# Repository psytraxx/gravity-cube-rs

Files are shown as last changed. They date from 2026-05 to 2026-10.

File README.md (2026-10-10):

# Gravity Cube - Rust Edition

A **fluid physics simulation** of gravity-responsive particles on a 3D LED cube, implemented in Rust using hexagonal architecture. Available in two flavors:

- **Firmware**: Runs on ESP32 hardware with BMI160 IMU and WS2812 LEDs
- **Desktop**: Interactive 3D visualization on macOS/Linux with GPU-accelerated rendering

Both versions share the same fluid physics simulation core with continuous particle movement, velocity tracking, and collision detection, demonstrating the power of hexagonal architecture for code reuse across platforms.

**Enclosure:** a 3D-printable translucent case for the cube. You can [view it in 3D and download the STLs](https://psytraxx.github.io/gravity-cube-rs/voxel-shell/viewer.html). Details are in [Enclosure](#-enclosure).

---

## Project Structure

This project uses a Cargo workspace with three crates:

```
gravity-cube-rs/
├── Cargo.toml              # Workspace root
├── core/                   # Platform-agnostic library
│   ├── src/
│   │   ├── effect.rs       # SimulationEffect trait
│   │   ├── effects/        # Simulation implementations (fluid, boids)
│   │   ├── physics_utils.rs # Shared physics utilities
│   │   └── types.rs        # Domain types (Particle, Vector3D, etc.)
│   └── Cargo.toml
├── firmware/               # ESP32 firmware
│   ├── src/
│   │   ├── main.rs         # Firmware entry point
│   │   └── adapters/       # BMI160 IMU, WS2812 LED adapters
│   ├── build.rs
│   ├── .cargo/config.toml  # ESP32 target configuration
│   └── Cargo.toml
├── case/                   # 3D-printable enclosure (published to GitHub Pages)
│   ├── concepts.html       # Comparison of five frame concepts
│   ├── voxel-shell/        # STLs, generator, fit checks, 3D viewer
│   └── voxel-shell-16x16/  # same enclosure for 16x16 flexible panels
└── desktop/                # Desktop simulator
    ├── shaders/            # WGSL shaders (vertex, fragment, wireframe)
    ├── src/
    │   ├── main.rs         # Desktop entry point
    │   ├── renderer3d.rs   # GPU-accelerated voxel renderer
    │   ├── camera.rs       # Static perspective camera
    │   ├── cube_transform.rs # Rotation and gravity transform
    │   └── input.rs        # Mouse/keyboard input handling
    └── Cargo.toml
```

---

## Architecture

Both versions follow **Hexagonal Architecture** (Ports and Adapters pattern): the core crate defines the domain and platform adapters feed it gravity and render its particles:

```
┌─────────────────────────────────────────────┐
│          Application Layer                  │
│   (ESP32 async / Desktop event loop)       │
└─────────────────┬───────────────────────────┘
                  │
┌─────────────────┴───────────────────────────┐
│          Domain Layer (core crate)          │
│  ┌─────────────────────────────────────┐   │
│  │ SimulationEffect Trait               │   │
│  │ - Common interface for all effects   │   │
│  └─────────────────────────────────────┘   │
│  ┌─────────────────────────────────────┐   │
│  │ Effect Implementations               │   │
│  │ - FluidSimulation (particle physics) │   │
│  │ - BoidsSimulation (flocking behavior)│   │
│  └─────────────────────────────────────┘   │
│  ┌─────────────────────────────────────┐   │
│  │ Physics Utilities                    │   │
│  │ - Boundary collision detection       │   │
│  │ - Speed clamping & distance calc     │   │
│  └─────────────────────────────────────┘   │
│  ┌─────────────────────────────────────┐   │
│  │ Domain Types                         │   │
│  │ - Particle (pos + velocity)          │   │
│  │ - Vector3D, Position, Pixel, Color   │   │
│  └─────────────────────────────────────┘   │
└─────────────────┬───────────────────────────┘
                  │
         ┌────────┴─────────┐
         │                  │
    ┌────┴─────┐      ┌─────┴────┐
    │ Firmware │      │ Desktop  │
    │ adapters │      │ adapters │
    ├──────────┤      ├──────────┤
    │ BMI160   │      │ Mouse/   │
    │ (gravity)│      │ keyboard │
    │ WS2812   │      │ (gravity)│
    │ (LEDs)   │      │ wgpu     │
    │          │      │ renderer │
    └──────────┘      └──────────┘
```

---

## 🎮 Desktop Simulator (macOS/Linux)

Interactive 3D visualization with GPU-accelerated rendering and fluid physics.

### Features

- **GPU Rendering**: wgpu 30-based instanced voxel rendering with WGSL shaders
- **Fluid Simulation**: 256 particles with continuous positions, velocity tracking, and collisions
- **Interactive Gravity**: Rotate cube with mouse/keyboard to change gravity direction
- **Real-time Updates**: Physics runs every frame (~60 FPS) for smooth animation
- **Visual Feedback**: Speed-based brightness using HSV color system

### Requirements

- macOS (Apple Silicon or Intel) or Linux
- Rust stable toolchain
- GPU with Vulkan/Metal/DX12 support

### Building

```bash
# Build desktop version (auto-detects target)
cargo build -p gravity-cube-desktop --release
```

### Running

```bash
# macOS
cargo run -p gravity-cube-desktop --release

# Linux (use X11 backend for best compatibility)
WINIT_UNIX_BACKEND=x11 cargo run -p gravity-cube-desktop --release

```

### Controls

- **Mouse Drag**: Rotate cube (changes gravity in local space)
- **Arrow Keys**: Alternative rotation (Up/Down = pitch, Left/Right = yaw)
- **Escape**: Exit

The cube rotates based on your input, and world gravity (always pointing down) is transformed into the cube's local coordinate system. This creates realistic fluid behavior as you tilt the cube!

### Configuration

The desktop uses `Config::default()` (see `core/src/types.rs`):

```rust
Config {
    cube_size: 8,
    num_particles: 256,
    delay_ms: 35,                // Firmware frame delay (desktop updates every frame)
    color: Color::DEFAULT,
}
```

The physics tuning constants (gravity, damping, max velocity, smoothing, decay, collision repulsion/damping) are compile-time constants at the top of `core/src/effects/fluid.rs`.

---

## 🔌 ESP32 Firmware

Runs on ESP32 hardware with real IMU sensor and LED cube.

### Hardware Requirements

- **MCU**: ESP32 (tested on ESP32, not ESP32-S3)
- **IMU**: BMI160 accelerometer (SPI)
- **LEDs**: 384× WS2812B (6 panels of 8×8)
- **LED Control**: RMT peripheral via GPIO 16

### Pin Configuration

**BMI160 IMU (SPI)**:
- MOSI: GPIO 23
- MISO: GPIO 19
- SCLK: GPIO 18
- CS: GPIO 5

**WS2812 LEDs (RMT)**:
- DATA: GPIO 16

### Prerequisites

1. Install ESP Rust toolchain:
```bash
# Install espup
cargo install espup

# Install ESP toolchain
espup install

# Source the environment (add to ~/.zshrc or ~/.bashrc)
. $HOME/export-esp.sh
```

2. Install espflash:
```bash
cargo install espflash
```

### Building

```bash
# Make sure the Xtensa toolchain (incl. xtensa-esp32-elf-gcc linker) is on PATH
. $HOME/export-esp.sh

# Navigate to firmware directory
cd firmware

# Build firmware
cargo build --release
```

### Flashing to ESP32

```bash
# Flash and monitor (automatically detects USB port)
cargo run --release

# Or specify port explicitly
espflash flash --monitor target/xtensa-esp32-none-elf/release/firmware
```

### Configuration

The firmware also uses `Config::default()` in `firmware/src/main.rs` (8×8×8 cube, 256 particles, 35ms frame delay, ~28 FPS). Override fields there if the ESP32 can't keep up, e.g. lower `num_particles`.

The physics tuning constants (gravity, damping, max velocity, smoothing, decay, collision repulsion/damping) are compile-time constants at the top of `core/src/effects/fluid.rs`.

### Troubleshooting

If BMI160 initialization fails:
- Check SPI wiring matches pin configuration above
- Verify 3.3V power supply to IMU
- Check SPI bus speed (1 MHz default)

If LEDs don't light:
- Verify GPIO 16 connection to LED data line
- Check 5V power supply to LED strips (384 LEDs draw significant current)
- Confirm LED count matches configuration (384 LEDs)

---

## 📦 Enclosure

The **Voxel Shell** is an 89.6 mm cube made of six mitred face shells, printed in translucent resin. Each shell holds one 65 × 66 mm WS2812 8×8 panel behind an 8×8 light grid and a diffuser skin, so every LED shows as a square pixel. A snap-in USB-C socket and an SS12F15 slide switch sit on the bottom front edge.

- [Interactive 3D viewer and STL downloads](https://psytraxx.github.io/gravity-cube-rs/voxel-shell/viewer.html)
- [Frame concepts that were compared](https://psytraxx.github.io/gravity-cube-rs/concepts.html)
- Source, parts list and assembly steps: [`case/voxel-shell/README.md`](case/voxel-shell/README.md)
- 16×16 version (183.6 mm cube, flexible 160 × 160 mm panels): [3D viewer](https://psytraxx.github.io/gravity-cube-rs/voxel-shell-16x16/viewer.html), [`case/voxel-shell-16x16/README.md`](case/voxel-shell-16x16/README.md)

The site is published from `case/` by `.github/workflows/pages.yml` on every push to `main` that changes it.

---

## 🔬 How It Works

### Fluid Physics Simulation (Shared Core)

1. **Gravity Input**:
   - Firmware: BMI160 accelerometer reads 3-axis acceleration
   - Desktop: World gravity transformed to cube's local coordinate system based on rotation

2. **Particle System**:
   - 256 particles by default (`Config::default()`)
   - Each particle has continuous f32 position (x, y, z) and velocity (vx, vy, vz) vectors
   - Particles initialized in bottom half of cube (like water filling halfway)

3. **Physics Update (every frame)**:
   - **Velocity Update**: `v = v * smoothing + (gravity * strength)`
     - Smoothing factor: 0.9 (creates smooth acceleration)
     - Gravity strength: 0.08
   - **Velocity Clamping**: Limit to ±0.6 max velocity
   - **Position Update**: `position += velocity`
   - **Boundary Collision**: Reflect velocity with 0.92 damping when hitting walls
   - **Velocity Decay**: `v *= 0.95` (simulates friction/air resistance)
   - **Particle Collision** (O(n²)):
     - Detect particles within distance < 1.0
     - Separate overlapping particles with repulsion force
     - Average velocities for energy conservation

4. **Display Update**:
   - Continuous particle positions rounded to nearest grid cell
   - Firmware: Map 3D grid positions to 2D LED panel indices
   - Desktop: Keep fastest particle per cell for brightness feedback, render with GPU instancing

### Panel Mapping (Firmware Only)

The physical LED cube has 6 panels, each with different orientations:

- Pre-computed lookup table (512 entries for 8³ positions)
- Handles rotations: 0°, 90°, 180°, 270°
- Applies X/Y axis inversions per panel
- Determines which panels each 3D position touches

### 3D Rendering (Desktop Only)

- **Instanced Voxel Rendering**: Single draw call for all visible voxels
- **Particle-to-Voxel Conversion**: Continuous positions rounded to discrete grid cells
- **Instance Data**: Voxel position (x,y,z), HSV-based color with speed brightness
- **WGSL Shaders** (in `desktop/shaders/`):
  - `vertex3d.wgsl`: Positions voxel instances with model transformation
  - `fragment3d.wgsl`: Directional lighting
  - `wireframe.wgsl`: Cube outline
- **Depth Buffer**: GPU handles depth sorting automatically

---

## 🏗️ Benefits of Hexagonal Architecture

1. **Code Reuse**: Same physics simulation runs on ESP32 and macOS
2. **Testability**: Domain logic can be tested without hardware
3. **Flexibility**: Easy to add new platforms (e.g., Raspberry Pi, Web)
4. **Maintainability**: Clear separation of concerns
5. **Portability**: Domain layer is platform-agnostic (no_std compatible)

---

## 🧪 Testing

The core library includes comprehensive unit tests for physics utilities and simulation effects.

### Running Tests

```bash
# Test core library (platform-agnostic)
cargo test -p gravity-cube-core

# Test desktop simulator
cargo test -p gravity-cube-desktop
```

### Note on Floating-Point Precision

The core library uses `micromath` for no_std compatibility, which provides fast approximations rather than exact floating-point calculations. Physics tests use tolerances of 0.01-0.02 to account for approximation errors (~2-3% for square roots). This prioritizes real-time performance over mathematical precision, which is appropriate for visual simulations.

---

## 🔍 Code Quality

After every code change, run clippy and fmt to keep the code clean:

```bash
# Format core and desktop (skip firmware — requires ESP toolchain)
cargo fmt -p gravity-cube-core -p gravity-cube-desktop

# Lint with warnings as errors
cargo clippy -p gravity-cube-core -p gravity-cube-desktop -- -D warnings
```

---

## 📦 Dependencies

### Shared (Core)
- `micromath`: Fast floating-point math (no_std compatible)

### Firmware
- `esp-hal`: ESP32 hardware abstraction
- `esp-rtos`: RTOS integration for Embassy
- `embassy-executor`, `embassy-time`: Async runtime
- `bmi160`: IMU driver
- `esp-hal-smartled`: WS2812 LED driver (RMT)

### Desktop
- `wgpu` (v30): GPU graphics API (Metal/Vulkan/DX12)
- `winit` (v0.30): Window and input handling
- `glam` (v0.34): 3D math library
- `pollster`: Async executor for setup
- `rand`: Random number generation
- `bytemuck`: Safe GPU buffer casting
- `log` + `env_logger`: Logging

---

## 🎯 Future Enhancements

- [ ] Web version (WASM + WebGPU)
- [ ] VR support (OpenXR)
- [ ] Network sync (control firmware from desktop)
- [ ] Multiple cube sizes (4×4×4, 16×16×16)
- [ ] Different physics modes (bounce, attract, repel)
- [ ] UI overlay for real-time parameter tweaking

---

## 📝 License

Same as the original Gravity Cube project.

Original C implementation: https://github.com/Oachristensen/Gravity-Cube

---

## 🙏 Credits

- **Original Project**: [Gravity Cube by Oachristensen](https://github.com/Oachristensen/Gravity-Cube)
- **Rust Port**: Implements the same physics with type safety and cross-platform support
- **Architecture**: Hexagonal (Ports & Adapters) pattern for maximum flexibility

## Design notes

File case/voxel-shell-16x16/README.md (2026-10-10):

# Voxel Shell 16×16 enclosure

The Voxel Shell scaled up for six flexible 160 × 160 mm WS2812 16×16 panels
(10 mm pitch, 256 LEDs each, 1536 LEDs in total). The design is the same as the
[8×8 Voxel Shell](../voxel-shell/README.md):

- six mitred, translucent face shells with funnel light cells;
- a 1.0 mm diffuser skin and every wall at least 1.0 mm;
- all 12 edges bevelled;
- a USB-C socket and SS12F15 switch on the bottom front bevel.

The result is a **183.6 mm** cube with a 174 mm lit area on each face.

Every STL here is generated by `../voxel-shell/generate.py` with
`VOXEL_PROFILE=16x16`, and all fit and printability checks pass.

View it in 3D: <https://psytraxx.github.io/gravity-cube-rs/voxel-shell-16x16/viewer.html>

## Files

| File | Qty | Purpose |
|---|---|---|
| `shell.stl` | 4 | Plain face shell (top, back, left, right) |
| `shell_port_front.stl` | 1 | Front shell with the USB-C cut-out and switch slot |
| `shell_port_bottom.stl` | 1 | Bottom shell with the matching relief |
| `fit_test.stl` | optional | 4 mm slice of a shell; order it first to test-fit a panel and backing sheet |
| `assembly_preview.stl` | – | Whole cube, for viewing only |
| `part_*.stl` | – | USB-C socket and switch reference models, in cube coordinates |
| `viewer.html` | – | Interactive 3D viewer |

Each shell is 180 × 180 × 10.3 mm and uses about 108 cm³ of resin, roughly 0.65 l for all six. Check that the print service's build volume takes 180 mm.

## The panel needs a backing sheet

A flexible panel will not stay flat in a 160 mm pocket. Glue each panel to a
**160 × 160 × 1 mm backing sheet**. Aluminium also spreads the LED heat; FR4 or
acrylic work too. Use thin double-sided tape or a thin layer of glue.

The shell's pocket is designed for a **1.6 mm stack**: flexible PCB (about 0.3–0.5 mm), adhesive and the 1 mm sheet.

- If your stack is thinner, shim it.
- If it is thicker, change `PCB_T` in the `16x16` block of `generate.py` and rebuild.

The pocket has 0.4 mm clearance on each side, so a 160.7 mm sheet still fits. A
0.6 mm ring of the shell rests on the panel margin, and the outermost light cells
are pulled 0.5 mm in from the panel edge to make room for it. The outer LEDs still
have 1.2 mm clearance; inner LEDs have 1.7 mm.

The connector and power leads on the back of the panel go into the cube
interior. The open channel along every edge carries wires between faces.

## Bought parts

| Qty | Part |
|---|---|
| 6 | Flexible WS2812 16×16 panel, 160 × 160 mm |
| 6 | Backing sheet 160 × 160 × 1 mm (aluminium, FR4 or acrylic) |
| 1 | Snap-in USB-C socket with leads (same as the 8×8 version) |
| 1 | SS12F15 slide switch |
| 48 | 2 mm dowel, about 5.5 mm long (four per edge) |

## Power

1536 WS2812 LEDs draw up to about **90 A at 5 V** at full white. A single USB-C
socket cannot supply that.

- Cap the global brightness in firmware: about 10–15 % keeps a typical animation
  near 5–10 A.
- Use a supply sized for the cap you choose.
- Feed power into every panel through its own voltage wires, not only through the data chain.

## Firmware

The simulation and firmware are still set up for an 8×8×8 cube. A 16×16 face
needs `cube_size: 16` and a 16×16 panel mapper.

## Rebuilding

```bash
cd case/voxel-shell
pip install manifold3d trimesh numpy rtree
VOXEL_PROFILE=16x16 python3 generate.py    # writes into case/voxel-shell-16x16/
VOXEL_PROFILE=16x16 python3 check_fit.py   # must end with "All checks passed."
```

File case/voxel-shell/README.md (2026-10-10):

# Voxel Shell enclosure

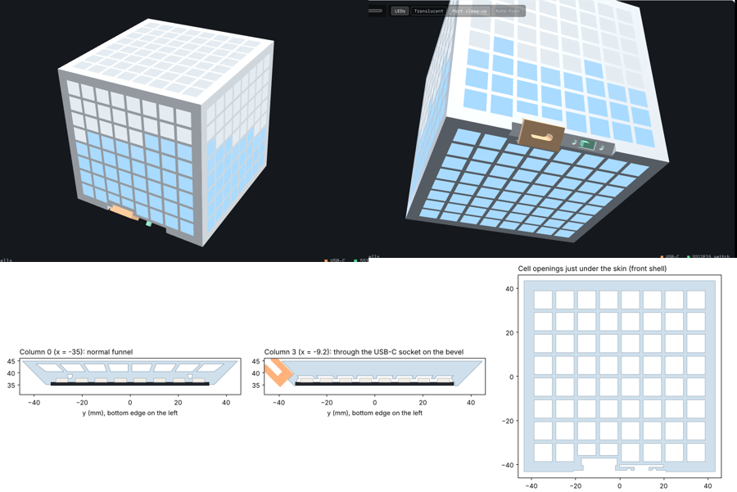
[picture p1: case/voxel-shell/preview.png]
Voxel Shell renders


An 89.6 mm cube built from six identical face shells with 45° mitred edges.
Each shell holds one 65 × 66 mm WS2812 8×8 panel (`../led_module.png`) in a
pocket. In front of the panel sits an 8×8 grid of funnel-shaped light cells and
a 1.0 mm diffuser skin, all printed as one translucent part. The cells start
at the LEDs (8.125 mm pitch) and fan out to a 10 mm pitch, so the pixels fill
80 mm of each 89.6 mm face with only a 4.8 mm rim at the edges.

All twelve edges carry a 45° bevel, 2.5 mm deep (a 5 mm facet) that stays
inside the unlit rim. The USB-C socket and the switch sit on the bevel of the
bottom front edge and point diagonally into the wedge between the front and
bottom panels. The four cells above them (columns 2–5, outer row on the front
and bottom faces) stop 5 mm short of the rim. Every other cell runs out to it.

Every wall is at least 1.0 mm, as PCBWay's review asked; the thinnest is the
1.0 mm diffuser skin. `check_fit.py` measures this, counting tapering wedges too.

## Files

| File | Qty | Notes |
|---|---|---|
| `shell.stl` | 4 | Plain face: top, back, left, right |
| `shell_port_front.stl` | 1 | USB-C cut-out and switch slot along its bottom edge |
| `shell_port_bottom.stl` | 1 | Matching relief for the port pockets; that edge faces the front shell |
| `fit_test.stl` | 1 | Optional, order first: a 4.9 mm slice of a shell (pocket, rim, bottom of the grid) to test-fit a real panel cheaply |
| `part_usb_c_socket.stl`, `part_usb_c_metal.stl`, `part_usb_c_lead_*.stl` | – | Reference model of the USB-C socket: clear housing with snap wings, metal receptacle, red and black leads (not printed) |
| `part_slide_switch_ss12f15.stl` | – | Reference model only (not printed) |
| `assembly_preview.stl` | – | All six shells assembled, for checking fit |
| `generate.py` | – | Parametric source; rebuilds every STL |
| `check_fit.py` | – | Interference checks (panels, LEDs, capacitors, parts, all panel orientations) |
| `viewer.html` | – | Interactive 3D viewer of the STLs (explode, translucent, port close-up) |

**Material:** translucent or clear resin (SLA) for all six shells. Sand or
bead-blast the outside for an even frosted diffusion.

## Bought parts

- 6 × WS2812 8×8 panel, 65 × 66 × 1.6 mm (LED grid 8.125 mm pitch, centred)
- 1 × snap-in USB-C socket with leads: flange 15.8 × 9.3 × 2.0, 9.0 deep behind the flange
- 1 × SS12F15 slide switch: plate 19.6 × 5.5, M2 holes 11.5 apart
- 24 × 2 mm dowel, about 5.5 mm long (1.75 mm filament works), for the mitre alignment holes

## Key dimensions

| | mm |
|---|---|
| Outer cube | 89.6 |
| PCB pocket | 65.5 × 66.5 × 1.6 (0.25 clearance per side) |
| Gap from panel back to the neighbour's edge | 1.5 (leaves a wire channel along every edge) |
| Lit area | 80 × 80 per face, 10 mm pixel pitch, 4.8 mm rim |
| Grid walls | 1.6 thick; vertical beside the LEDs (0.76 clear, 0.26 if the grid is 0.5 off-centre on the 66 side), then fanning out; stop 1.3 above the PCB (clears capacitors) |
| PCB front to diffuser skin | 7.7 |
| Diffuser skin | 1.0 |
| Clamp ring on the PCB margin | 0.6 (outer LEDs start 1.56 from the 65 mm edges) |
| Edge bevel | 45°, 2.5 deep (5 mm facet), on all twelve edges |
| USB-C cut-out | 14.6 × 8.6 in a 1.6 wall; the flange (15.8 × 9.3) stays on the outside and covers it |
| Switch lever slot | 6.6 × 2.6 in a 2.1 wall; the switch is glued in |

`USB_CUTOUT` is an estimate: the drawing only gives the flange size. Measure
the body of your socket behind the flange and change it in `generate.py`
before ordering.

## Assembly

1. Press each panel into its shell, LEDs towards the grid. The pocket is
   65.5 × 66.5, so the 66 mm side goes along the long side of the pocket. A few dots of glue
   on the PCB rim hold it.
2. Push the USB-C socket into the bevel from outside. Glue the
   switch to the inside of the bevel wall so its lever comes through the slot.
   Both pockets are split between the front and bottom port shells, so fit
   the parts after those two shells are joined.
3. Wire the panels, ESP32 and battery. The channel along every edge (between
   panel backs and the neighbouring shells) carries wires from face to face,
   and both port pockets open into it.
4. Put dowels in the mitre holes and close the cube. Glue the last face, or
   leave it dry-fitted so the cube can be opened again.

## Viewing

Online: <https://psytraxx.github.io/gravity-cube-rs/voxel-shell/viewer.html>
(published from `case/` by `.github/workflows/pages.yml`).

Locally, browsers won't load STL files from `file://`, so serve the folder:

```bash
cd case/voxel-shell && python3 -m http.server 8000
# open http://localhost:8000/viewer.html
```

The viewer's **Plasma** button swaps the water for one big plasma animation that
flows over all six faces and across the edges.

`../concepts.html` compares the five frame concepts considered (Edge Rails,
Corner Bumpers, Lantern Cage, Pinwheel, Voxel Shell) and opens directly.

## Rebuilding

```bash
pip install manifold3d trimesh numpy rtree
python3 generate.py
python3 check_fit.py   # must end with "All checks passed."
```

All dimensions are constants at the top of `generate.py`. `VOXEL_PROFILE=16x16`
builds the 183.6 mm version for flexible 160 × 160 mm 16×16 panels into
[`../voxel-shell-16x16/`](../voxel-shell-16x16/README.md).

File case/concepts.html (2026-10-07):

# Gravity Cube frame concepts

Five frame designs for six 65 × 65 mm WS2812 8×8 panels together as a cube. Each one is drawn to scale in millimetres. Drag to turn the cube. The lit "water" always settles toward the bottom, just like the running simulation. The bottom front edge has the USB-C port and power switch.

1.56 mmGap between the PCB edge and the outer LED rows. Any front lip must stay under this, so these concepts use 1.2 mm.

1.6 × 1.6 mmOpen notch along every cube edge when six square boards sit around a 65 mm core.

8.125 mmLED pitch (65 / 8). Every millimetre of frame at an edge widens the gap between the pixels on either side of that edge.

Material Resin black Resin white Nylon TPU Aluminium

LEDs on Auto-turn Port close-up

——

USB-C port and power switch

WhereThe six panels close the cube on every side, so the port can't go through a face. Each concept puts a USB-C socket (about 9 × 3.3 mm) and a small slide switch in a frame "pod" on the bottom front edge, drawn in the viewer.

Wiring inFour thin wires (28–30 AWG: 5 V, GND, and the battery through the switch) run from the pod through one of the panel's roughly 2 mm mounting holes. The ESP32 and battery can go in later without touching the frame.

AlternativeIn the Lantern Cage, the panels can sit 3.5 mm off the core. That opens a channel under every rail, so the socket board fits inside the rail and no holes are needed.

Materials, from your print service list

Material | Verdict | Best for | Why

Side by side

Concept | Outer size | Printed parts | Covers LEDs? | Drop protection | Print effort | Material

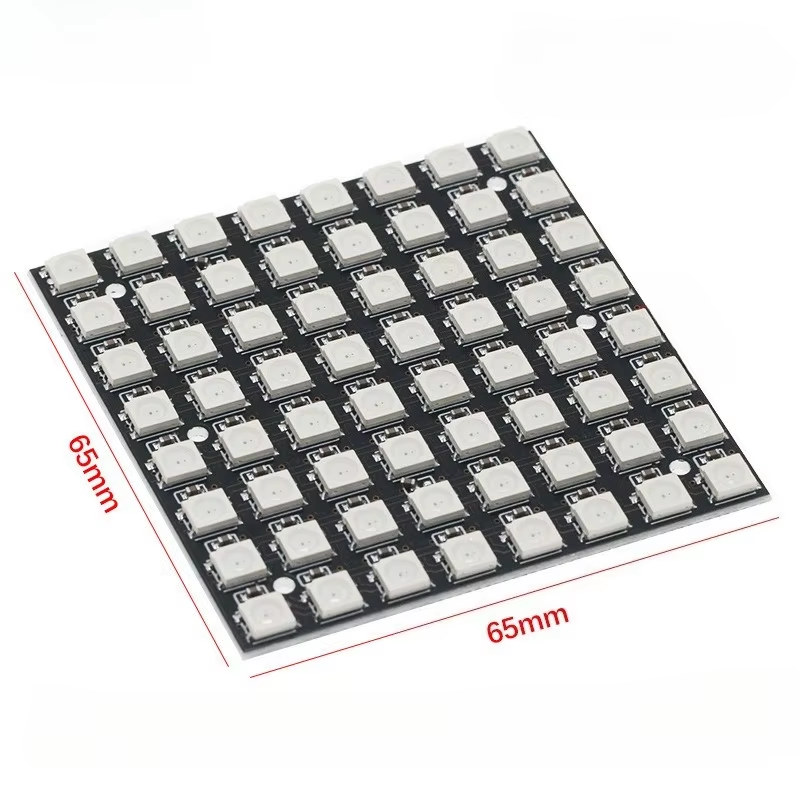
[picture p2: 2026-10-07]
case/led_module.png

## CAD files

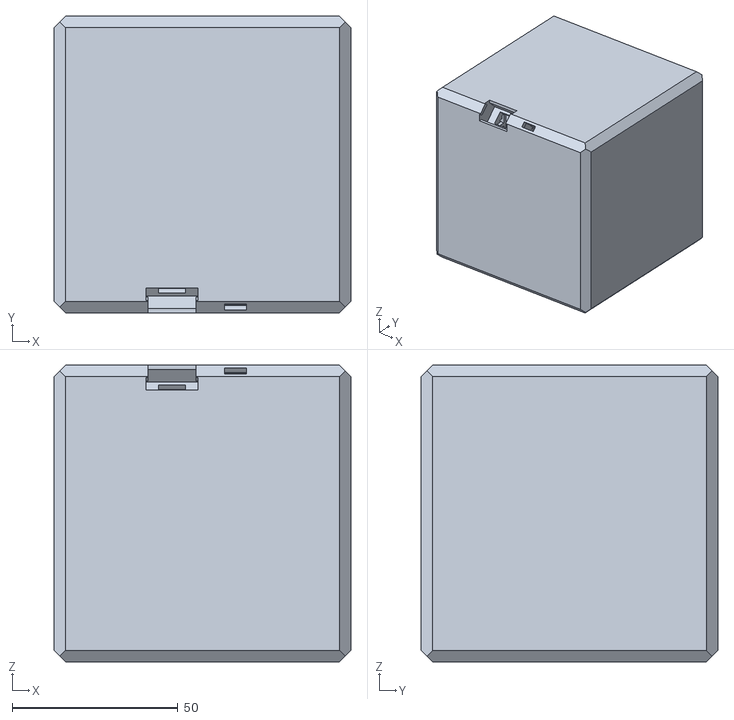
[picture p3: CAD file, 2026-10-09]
case/voxel-shell/assembly_preview.stl
89.6 x 89.6 x 89.6

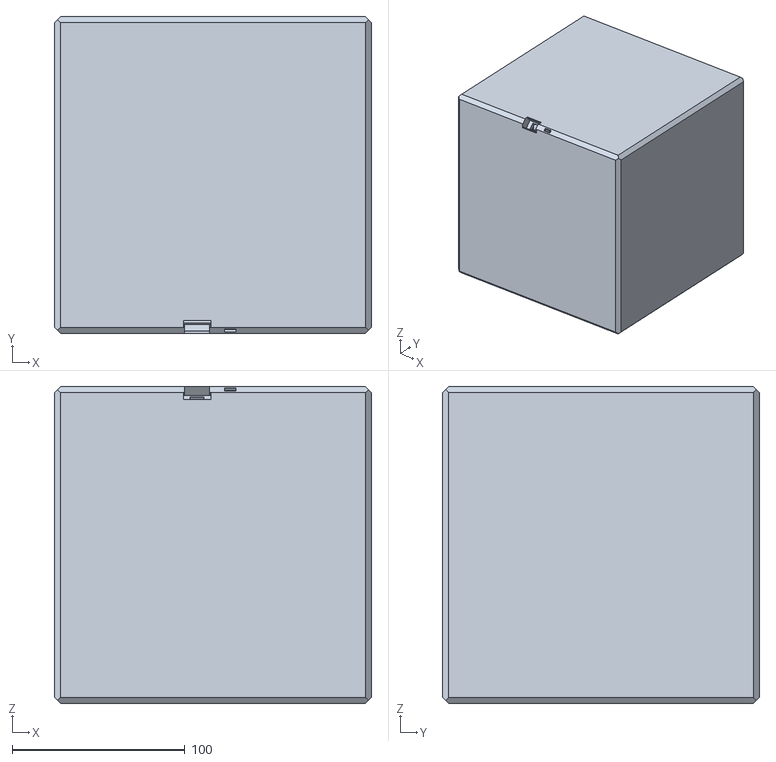
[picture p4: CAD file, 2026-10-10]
case/voxel-shell-16x16/assembly_preview.stl
183.6 x 183.6 x 183.6

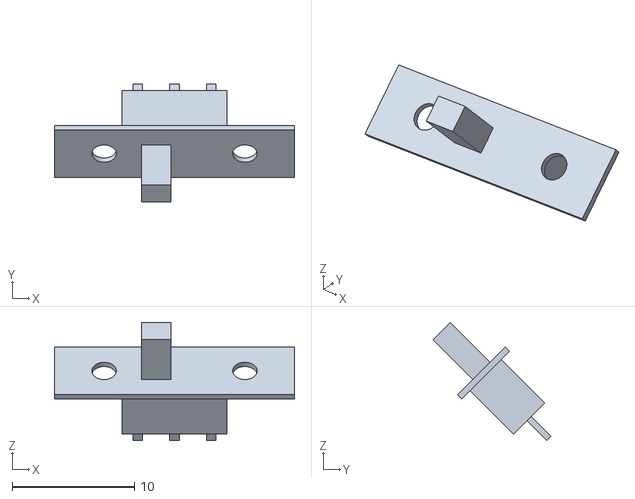
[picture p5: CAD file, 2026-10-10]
case/voxel-shell-16x16/part_slide_switch_ss12f15.stl
19.6 x 9.65 x 9.65

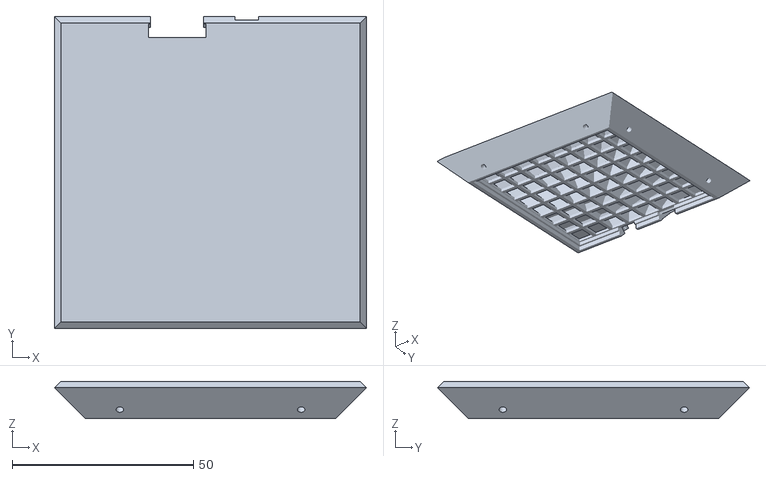
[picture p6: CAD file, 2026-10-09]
case/voxel-shell/shell_port_bottom.stl
86.1 x 86.1 x 10.3

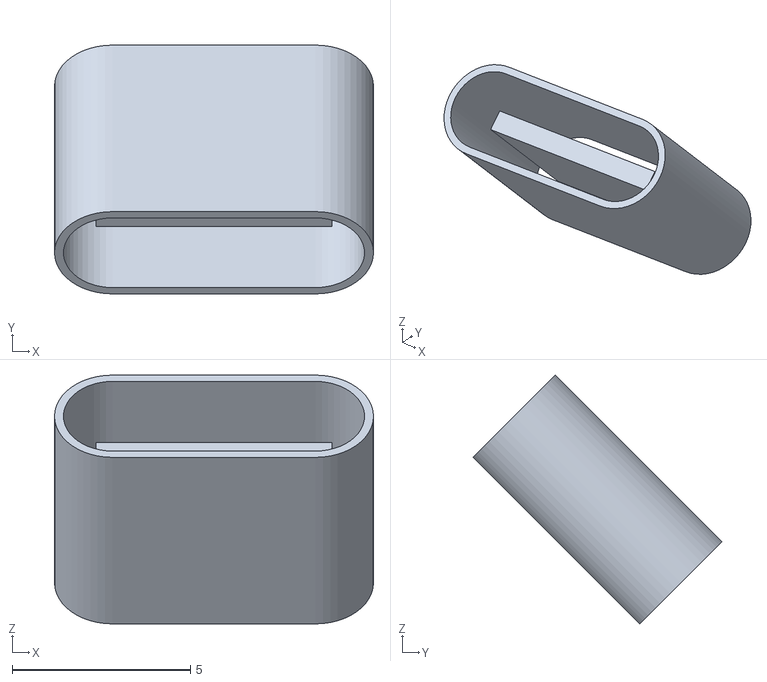
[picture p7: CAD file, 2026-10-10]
case/voxel-shell-16x16/part_usb_c_metal.stl
8.94 x 6.97 x 6.97

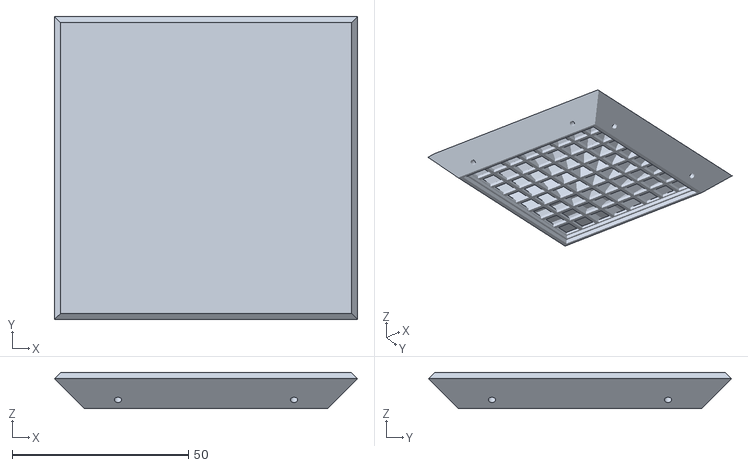
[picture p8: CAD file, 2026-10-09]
case/voxel-shell/shell.stl
86.1 x 86.1 x 10.3

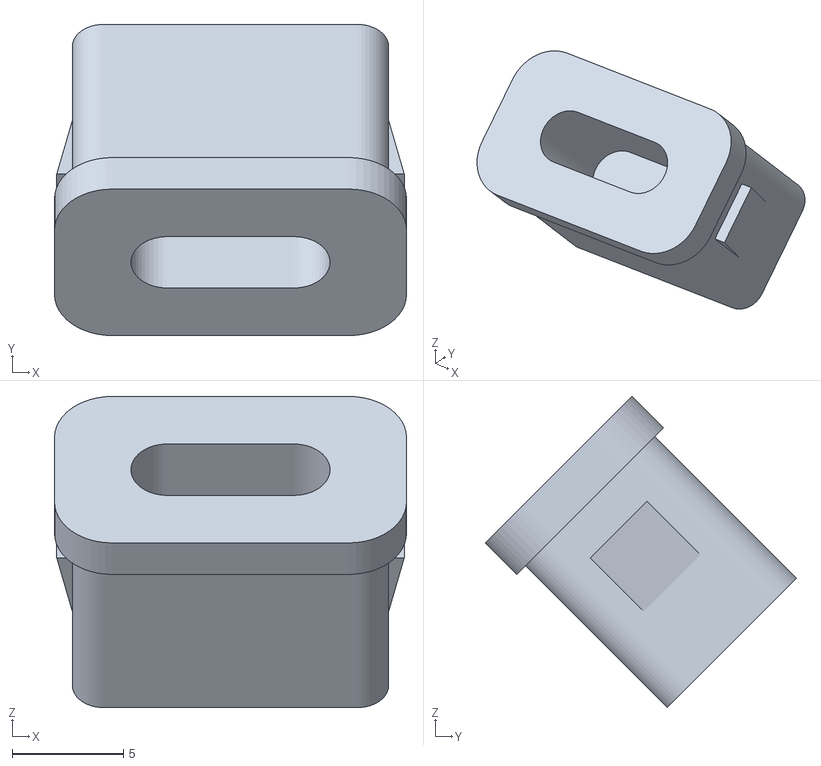
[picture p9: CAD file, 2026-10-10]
case/voxel-shell-16x16/part_usb_c_socket.stl
15.8 x 14.0 x 14.0

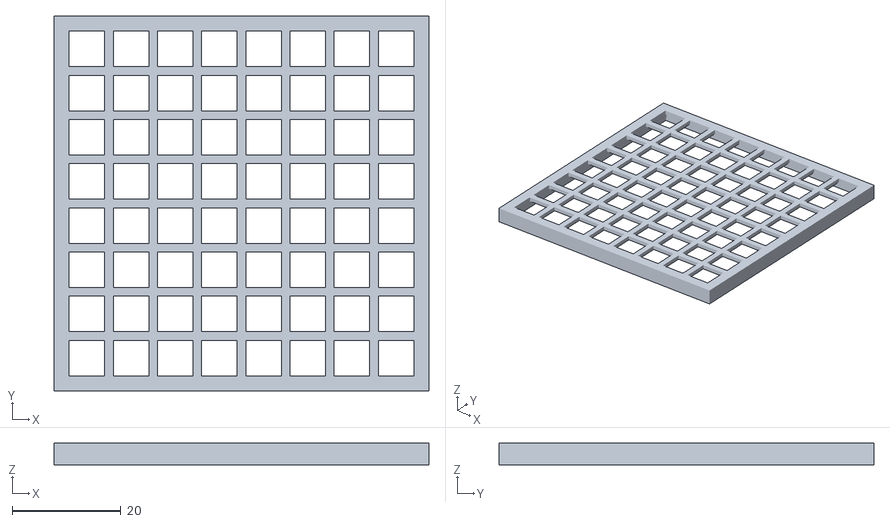
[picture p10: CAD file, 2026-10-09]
case/voxel-shell/fit_test.stl
69.0 x 69.0 x 4.00

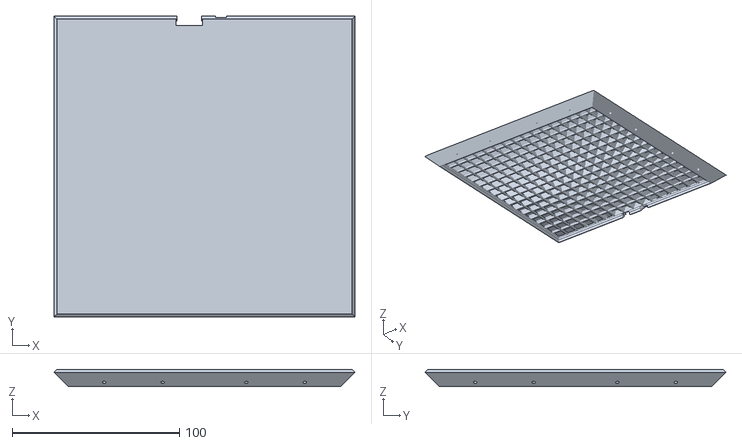
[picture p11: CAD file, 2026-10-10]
case/voxel-shell-16x16/shell_port_bottom.stl
180.1 x 180.1 x 10.3

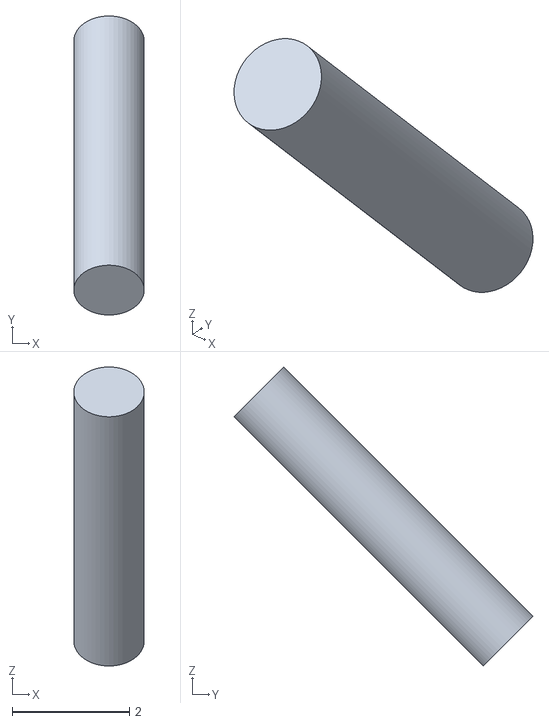
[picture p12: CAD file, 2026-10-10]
case/voxel-shell-16x16/part_usb_c_lead_red.stl
1.20 x 5.09 x 5.09

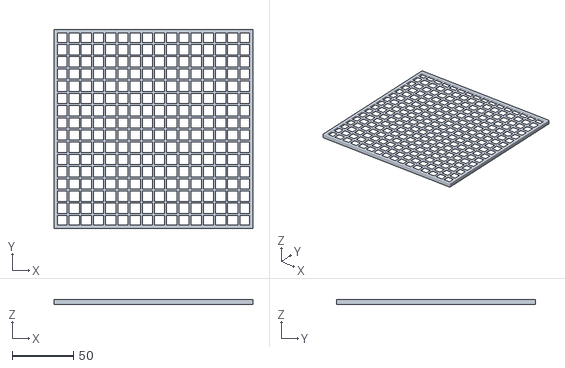
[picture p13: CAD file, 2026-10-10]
case/voxel-shell-16x16/fit_test.stl
163.0 x 163.0 x 4.00

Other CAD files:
case/voxel-shell/part_slide_switch_ss12f15.stl
case/voxel-shell/shell_port_front.stl
case/voxel-shell-16x16/shell.stl
case/voxel-shell/part_usb_c_socket.stl
case/voxel-shell-16x16/shell_port_front.stl
case/voxel-shell/part_usb_c_lead_red.stl
case/voxel-shell/part_usb_c_metal.stl
case/voxel-shell-16x16/part_usb_c_lead_black.stl
case/voxel-shell/part_usb_c_lead_black.stl

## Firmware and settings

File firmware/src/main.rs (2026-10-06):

#![no_std]
#![no_main]
#![deny(
    clippy::mem_forget,
    reason = "mem::forget is generally not safe to do with esp_hal types, especially those \
    holding buffers for the duration of a data transfer."
)]

use embassy_executor::Spawner;
use embassy_time::{Duration, Timer};
use esp_backtrace as _;
use esp_hal::clock::CpuClock;
use esp_hal::delay::Delay;
use esp_hal::gpio::{Level, OutputConfig};
use esp_hal::rmt::Rmt;
use esp_hal::spi::master::Config as SpiConfig;
use esp_hal::spi::master::Spi;
use esp_hal::time::Rate;
use esp_hal::timer::timg::TimerGroup;
use log::{info, warn};
use micromath::F32Ext;

extern crate alloc;

use esp_hal_smartled::{RmtSmartLeds, WS2812_TIMING, buffer_size, color_order};
use gravity_cube_core::{Config, Simulation, SimulationEffect, Vector3D, Vector3DExt};
use smart_leds::RGB8;

mod adapters;
use adapters::{Bmi160Adapter, Ws2812Display};

// This creates a default app-descriptor required by the esp-idf bootloader.
esp_bootloader_esp_idf::esp_app_desc!();

#[esp_rtos::main]
async fn main(_spawner: Spawner) -> ! {
    esp_println::logger::init_logger_from_env();

    let config = esp_hal::Config::default().with_cpu_clock(CpuClock::max());
    let peripherals = esp_hal::init(config);

    esp_alloc::heap_allocator!(#[unsafe(link_section = ".dram2_uninit")] size: 98767);

    let timg0 = TimerGroup::new(peripherals.TIMG0);
    esp_rtos::start(timg0.timer0, peripherals.FROM_CPU_INTR0);

    info!("╔═══════════════════════════════════════╗");
    info!("║   Gravity Cube - Rust Edition v0.1   ║");
    info!("╚═══════════════════════════════════════╝");
    info!("");

    // ========================================
    // Hardware Configuration
    // ========================================
    info!("Configuring hardware peripherals...");

    // Pin assignments for BMI160 IMU (SPI):
    // - MOSI:  GPIO 23
    // - MISO:  GPIO 19
    // - SCLK:  GPIO 18
    // - CS:    GPIO 5

    // Pin assignment for WS2812 LEDs (RMT):
    // - DATA:  GPIO 16 (changed from 37 for ESP32 compatibility)

    // Initialize SPI for BMI160 IMU
    info!("  • Setting up SPI for BMI160 IMU...");
    let config = SpiConfig::default().with_frequency(Rate::from_mhz(1));
    let spi_bus = Spi::new(peripherals.SPI2, config) // 1 MHz for BMI160
        .expect("Failed to create SPI")
        .with_sck(peripherals.GPIO18)
        .with_mosi(peripherals.GPIO23)
        .with_miso(peripherals.GPIO19);

    let cs = esp_hal::gpio::Output::new(peripherals.GPIO5, Level::High, OutputConfig::default());
    let spi_device = embedded_hal_bus::spi::ExclusiveDevice::new(spi_bus, cs, Delay::new())
        .expect("Failed to create SPI device");

    // Initialize BMI160 IMU
    let mut imu_opt = match Bmi160Adapter::new(spi_device) {
        Ok(imu) => {
            info!("  ✓ BMI160 IMU initialized successfully");
            Some(imu)
        }
        Err(_) => {
            warn!("  ✗ Failed to initialize BMI160 IMU");
            warn!("    Check your wiring:");
            warn!("      MOSI → GPIO 23");
            warn!("      MISO → GPIO 19");
            warn!("      SCLK → GPIO 18");
            warn!("      CS   → GPIO 5");
            warn!("    Continuing with default gravity (pointing down)");
            None
        }
    };

    // Initialize RMT for WS2812 LEDs
    info!("  • Setting up RMT for WS2812 LEDs...");
    let rmt_freq = Rate::from_mhz(80);
    let rmt = Rmt::new(peripherals.RMT, rmt_freq)
        .expect("Failed to create RMT")
        .into_async();

    // Create RMT channel for WS2812 on GPIO 16
    // Buffer size for 384 LEDs
    let led_driver = RmtSmartLeds::<{ buffer_size::<RGB8>(384) }, _, RGB8, color_order::Grb>::new(
        WS2812_TIMING,
        rmt.channel0,
        peripherals.GPIO16,
        rmt_freq,
    )
    .expect("Failed to create LED driver");

    let mut display = Ws2812Display::new(led_driver, 384);
    info!("  ✓ WS2812 LED driver initialized (384 LEDs on GPIO 16)");

    info!("");
    info!("Hardware initialization complete!");
    info!("");

    // ========================================
    // Simulation Configuration
    // ========================================
    info!("Initializing physics simulation...");

    let sim_config = Config::default();

    let mut simulation = Simulation::new(sim_config);
    simulation.populate(sim_config.num_particles);

    info!(
        "  • Cube size: {}x{}x{}",
        sim_config.cube_size, sim_config.cube_size, sim_config.cube_size
    );
    info!("  • Active particles: {}", sim_config.num_particles);
    info!("  • Update rate: {}ms", sim_config.delay_ms);
    info!(
        "  • LED color: RGB({}, {}, {})",
        sim_config.color.r, sim_config.color.g, sim_config.color.b
    );
    info!("");

    // Wait for sensors to stabilize
    Timer::after(Duration::from_secs(1)).await;

    info!("Starting main loop...");
    info!("═══════════════════════════════════════");
    info!("");

    // ========================================
    // Main Loop
    // ========================================
    let mut loop_count = 0u32;

    loop {
        // Read acceleration from IMU (includes magnitude, not just direction)
        // This makes particles respond to shaking and sudden movements
        let acceleration = if let Some(ref mut imu) = imu_opt {
            match imu.read_acceleration() {
                Ok(a) => a,
                Err(_) => {
                    warn!("Failed to read IMU, using default gravity");
                    Vector3D::new(0.0, 0.0, -1.0)
                }
            }
        } else {
            // No IMU available, use default gravity
            Vector3D::new(0.0, 0.0, -1.0)
        };

        // Run physics simulation step with actual acceleration
        simulation.step(&acceleration);

        // Clear display
        if let Err(e) = display.clear().await {
            warn!("Display clear failed: {:?}", e);
        }

        // Update display with active pixels
        for pixel in simulation.active_pixels() {
            if let Err(e) = display.set_pixel(pixel.position, sim_config.color).await {
                warn!("Failed to set pixel at {:?}: {:?}", pixel.position, e);
            }
        }

        // Refresh display to show changes
        if let Err(e) = display.refresh().await {
            warn!("Display refresh failed: {:?}", e);
        }

        // Log status periodically (every 100 loops)
        loop_count = loop_count.wrapping_add(1);
        if loop_count.is_multiple_of(100) {
            let active_count = simulation.active_pixels().count();
            let magnitude = (acceleration.x * acceleration.x
                + acceleration.y * acceleration.y
                + acceleration.z * acceleration.z)
                .sqrt();
            info!(
                "Loop {}: {} particles, accel: ({:.2}, {:.2}, {:.2}) |{:.2}|g",
                loop_count, active_count, acceleration.x, acceleration.y, acceleration.z, magnitude
            );
        }

        // Delay for next frame
        Timer::after(Duration::from_millis(sim_config.delay_ms as u64)).await;
    }
}

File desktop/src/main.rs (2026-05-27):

mod camera;
mod cube_transform;
mod input;
mod renderer3d;

use cube_transform::CubeTransform;
use gravity_cube_core::{Config, Simulation, SimulationEffect, Vector3DExt};
use input::InputHandler;
use renderer3d::{RenderError, Renderer3D};
use std::sync::Arc;
use winit::{
    application::ApplicationHandler,
    event::*,
    event_loop::{ActiveEventLoop, EventLoop},
    keyboard::{KeyCode, PhysicalKey},
    window::{Window, WindowAttributes, WindowId},
};

const WINDOW_WIDTH: u32 = 1400;
const WINDOW_HEIGHT: u32 = 1400;

struct App {
    state: Option<State>,
    window: Option<Arc<Window>>,
}

struct State {
    renderer: Renderer3D,
    simulation: Simulation,
    input_handler: InputHandler,
    cube_transform: CubeTransform,
    last_update: std::time::Instant,
}

impl State {
    async fn new(window: Arc<Window>) -> Self {
        // Initialize simulation with fluid physics
        let config = Config::default();

        let renderer = Renderer3D::new(window, config.color).await;

        let mut simulation = Simulation::new(config);
        simulation.populate(config.num_particles);

        let input_handler = InputHandler::new(WINDOW_WIDTH, WINDOW_HEIGHT);
        let cube_transform = CubeTransform::new();

        Self {
            renderer,
            simulation,
            input_handler,
            cube_transform,
            last_update: std::time::Instant::now(),
        }
    }

    fn update(&mut self) {
        let now = std::time::Instant::now();
        let _dt = now.duration_since(self.last_update).as_secs_f32();
        self.last_update = now;

        // Update cube rotation from mouse drag
        let (mouse_dx, mouse_dy) = self.input_handler.get_mouse_delta();

        // Update cube rotation from keyboard
        let (kbd_dx, kbd_dy) = self.input_handler.get_keyboard_delta();

        // Combine mouse and keyboard rotation
        let delta_x = mouse_dx + kbd_dx;
        let delta_y = mouse_dy + kbd_dy;

        if delta_x.abs() > 0.0 || delta_y.abs() > 0.0 {
            self.cube_transform.rotate(delta_x, -delta_y);
            self.renderer.update_cube_transform(&self.cube_transform);
        }

        // Get gravity in cube's local space
        // World gravity is always down, but transformed to cube's rotated coordinate system
        let accel_glam = self.cube_transform.get_local_gravity();

        // Convert glam::Vec3 to gravity_cube_core::Vector3D
        let acceleration =
            gravity_cube_core::Vector3D::new(accel_glam.x, accel_glam.y, accel_glam.z);

        // Update physics (every frame for smooth animation)
        self.simulation.step(&acceleration);
    }

    fn render(&mut self) -> Result<(), RenderError> {
        self.renderer.render(self.simulation.particles())
    }

    fn resize(&mut self, new_size: winit::dpi::PhysicalSize<u32>) {
        self.renderer.resize(new_size);
    }

    fn input(&mut self, event: &WindowEvent) -> bool {
        match event {
            WindowEvent::CursorMoved { position, .. } => {
                self.input_handler.update_mouse_position(*position);
                true
            }
            WindowEvent::MouseInput { state, button, .. } => {
                if *button == winit::event::MouseButton::Left {
                    match state {
                        ElementState::Pressed => {
                            self.input_handler.start_drag(self.input_handler.mouse_pos);
                        }
                        ElementState::Released => {
                            self.input_handler.end_drag();
                        }
                    }
                    return true;
                }
                false
            }
            WindowEvent::KeyboardInput {
                event:
                    KeyEvent {
                        physical_key: PhysicalKey::Code(key_code),
                        state,
                        ..
                    },
                ..
            } => {
                // Handle arrow keys for rotation
                let pressed = *state == ElementState::Pressed;
                self.input_handler.handle_keyboard(*key_code, pressed);

                // Don't consume the event so Escape can still close the window
                matches!(
                    key_code,
                    KeyCode::ArrowLeft
                        | KeyCode::ArrowRight
                        | KeyCode::ArrowUp
                        | KeyCode::ArrowDown
                )
            }
            _ => false,
        }
    }
}

impl ApplicationHandler for App {
    fn resumed(&mut self, event_loop: &ActiveEventLoop) {
        if self.window.is_none() {
            let window_attributes = WindowAttributes::default()
                .with_title("Gravity Cube - Fluid Simulation")
                .with_inner_size(winit::dpi::PhysicalSize::new(WINDOW_WIDTH, WINDOW_HEIGHT))
                .with_resizable(true);

            let window = Arc::new(event_loop.create_window(window_attributes).unwrap());
            self.state = Some(pollster::block_on(State::new(window.clone())));
            self.window = Some(window);
        }
    }

    fn window_event(&mut self, event_loop: &ActiveEventLoop, _id: WindowId, event: WindowEvent) {
        let (Some(state), Some(window)) = (self.state.as_mut(), self.window.as_ref()) else {
            return;
        };

        if !state.input(&event) {
            match event {
                WindowEvent::CloseRequested
                | WindowEvent::KeyboardInput {
                    event:
                        KeyEvent {
                            state: ElementState::Pressed,
                            physical_key: PhysicalKey::Code(KeyCode::Escape),
                            ..
                        },
                    ..
                } => event_loop.exit(),
                WindowEvent::Resized(physical_size) => {
                    state.resize(physical_size);
                }
                WindowEvent::RedrawRequested => {
                    state.update();
                    match state.render() {
                        Ok(_) => {}
                        Err(RenderError::Lost) => state.resize(window.inner_size()),
                    }
                }
                _ => {}
            }
        }
    }

    fn about_to_wait(&mut self, _event_loop: &ActiveEventLoop) {
        if let Some(window) = self.window.as_ref() {
            window.request_redraw();
        }
    }
}

fn main() {
    env_logger::init();

    let event_loop = EventLoop::new().unwrap();
    let mut app = App {
        state: None,
        window: None,
    };

    event_loop.run_app(&mut app).unwrap();
}

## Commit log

2025-11-17 Refactor code structure and update dependencies
    - Removed .vscode directory from .gitignore
    - Updated embedded-hal-bus version to 0.3.0 in Cargo.toml and Cargo.lock
    - Simplified Bmi160Adapter by removing delay parameter
    - Changed WS2812 LED GPIO from 37 to 16 for ESP32 compatibility
    - Updated DisplayPort and ImuPort traits to use async functions
    - Added CHIP_CONFIGURATION.md for chip configuration notes
2025-11-17 Implement SimpleRng using ESP32 hardware RNG
2025-11-17 Update dependencies and improve error handling
    - Bump version of `delegate` from 0.13.4 to 0.13.5 in Cargo.lock
    - Remove `heapless` dependency from Cargo.toml
    - Enhance error logging in display operations in main.rs
    - Optimize pixel movement tracking in simulation.rs using a bitset
    [main.rs]
2026-05-27 Update dependencies and improve build scripts
    - Updated `esp-hal` from version 1.0.0 to 1.1.1.
    - Updated `esp-rtos` from version 0.2.0 to 0.3.0.
    - Updated `esp-bootloader-esp-idf` from version 0.4.0 to 0.5.0.
    - Updated `log` from version 0.4.27 to 0.4.30.
    - Updated `embassy-executor` from version 0.9.1 to 0.10.0.
    - Updated `embassy-time` from version 0.5.0 to 0.5.1.
    - Updated `esp-alloc` from version 0.9.0 to 0.10.0.
    - Updated `esp-backtrace` from version 0.18.1 to 0.19.0.
    - Updated `esp-println` from version 0.16.1 to 0.17.0.
    - Updated `rand_core` from version 0.10.0 to 0.10.1.
    - Changed the GitHub repository for `esp-hal-smartled`.
    - Improved error messages in `build.rs` for missing symbol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
    [main.rs]
2026-05-27 Desktop (#1)
    * desktop version
    * Enhance CI workflow by integrating sccache for caching and performance improvements
    * Enhance documentation and code quality guidelines; introduce RenderError enum for better error handling in rendering
    [bmi160.rs]
2026-08-02 Update all non-major dependencies (patch) (#10)
    * Update all non-major dependencies
    * fix(desktop): migrate off glam camera fns deprecated in 0.33
    glam 0.33 deprecated Mat4::look_at_rh and Mat4::perspective_rh in favour
    of the glam::camera modules. Clippy runs with -D warnings in CI, so the
    deprecation warnings broke the Desktop & Core job.
    Uses camera::rh::view::look_at_mat4 and camera::rh::proj::directx::perspective
    (directx = 0..1 depth range, matching wgpu). Both were verified to produce
    matrices bit-identical to the deprecated functions they replace.
    Claude-Session: https://claude.ai/code/session_01QgVgdk4CKJRu2MyrLVK4Wx
    -------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
2026-08-02 Update Rust crate wgpu to v30 (#13)
    * Update Rust crate wgpu to v30
    * fix(desktop): migrate renderer to the wgpu 30 API
    wgpu 30 changed four things this renderer relies on:
    - RequestAdapterOptions gained apply_limit_buckets (false = old behaviour)
    - SurfaceConfiguration gained color_space (Auto = pre-30 behaviour)
    - VertexState::buffers is now &[Option<VertexBufferLayout>]
    - presentation moved from SurfaceTexture::present to Queue::present
    Behaviour is unchanged; the new fields take the values that reproduce
    wgpu 29 semantics.
    ---------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
    [renderer3d.rs]
2026-10-06 Fix desktop and firmware build after dependency updates
    Bump esp-rom-sys to 0.1.5, port firmware to esp-rtos 0.4 and
    esp-hal-smartled 0.18 APIs, and update README versions and build notes.
    [main.rs]
2026-10-07 Add LED module image to the case directory
2026-10-07 Add Voxel Shell enclosure for the LED cube (#16)
    * Add Voxel Shell enclosure STLs for the LED cube
    Six mitred, translucent face shells, each holding a 65 mm WS2812 panel
    behind an 8x8 light grid and a diffuser skin. Two variants carry a snap-in
    USB-C socket and an SS12F15 slide switch on the bottom front edge.
    Includes the parametric generator and reference models of both parts.
    Claude-Session: https://claude.ai/code/session_016KN27yLYFtR8rfzYRixKWo
    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
    [assembly_preview.stl, fit_test.stl, part_slide_switch_ss12f15.stl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]
2026-10-07 Publish enclosure to GitHub Pages; build Rust only on Rust changes (#17)
    - pages.yml deploys case/ to GitHub Pages on pushes to main that touch
    it: a landing page, the Voxel Shell 3D viewer (now with STL download
    links) and the frame concepts page. The README links to them.
    - rust_ci.yml gains a paths-filter job. Firmware builds only when
    firmware/, core/, the workspace Cargo files or the workflow change, and
    Desktop & Core only for desktop/, core/ and the same shared files.
    Skipped jobs still count as passed for required checks.
    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
2026-10-07 Replace Rust CI paths-filter with paths-ignore for case/ (#18)
    Revert the dorny/paths-filter job and per-job conditions. Instead, the
    whole Continuous Integration workflow skips pushes and pull requests
    that only change files under case/ (the enclosure and its Pages site).
    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
2026-10-08 Voxel Shell: funnel cells, 45° port bevel, detailed USB-C model (#19)
    * Voxel Shell: funnel light cells for an 80 mm lit area
    The light cells now start straight beside the LEDs (8.125 mm pitch) and
    fan out to a 10 mm pitch at the diffuser skin, so the pixels fill 80 mm
    of each 89.6 mm face with a 4.8 mm rim instead of a 13 mm border.
    Along the bottom front edge, columns 2-5 keep their bottom three rows
    inside the LED grid to leave room for the USB-C socket and switch;
    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
    [assembly_preview.stl, fit_test.stl, part_slide_switch_ss12f15.stl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]
2026-10-08 Voxel Shell: bevel all edges, meet PCBWay 0.8 mm wall rule (#20)
    - Every cube edge now has the 45 degree, 2.5 mm bevel that the ports sit
    on. It replaces the knife edge where each mitre met the skin, which
    measured ~0 mm thick.
    - Cell walls stay vertical at least 0.9 mm above the grid floor, so the
    ledge where the outer wall turns outward is no longer 0.5 mm.
    - Port section: cells above the socket and switch (columns 2-5) stop at
    36 mm; the USB-C pocket is flange-wide and its 45 degree wedges under
    the faces are squared off; the switch wall is 1.6 mm and the screw
    holes are gone (glue the switch); the wire channels are 4.4 mm tall so
    they take out the board-pocket lips instead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
    [assembly_preview.stl, fit_test.stl, part_slide_switch_ss12f15.stl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]
2026-10-08 Voxel Shell: 0.8 mm diffuser skin (#21)
    Thinner skin for more light through the translucent resin. The light
    cells are 0.4 mm deeper so the cube stays 89.6 mm and everything else
    (bevel, ports, rim) keeps its place. The skin is now the thinnest wall,
    at PCBWay's 0.8 mm SLA minimum; check_fit.py passes.
    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
    [assembly_preview.stl, fit_test.stl, shell.stl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]
2026-10-09 Voxel Shell: 1.0 mm minimum walls (PCBWay review), plasma viewer mode (#22)
    * Voxel Shell viewer: plasma mode across all six faces
    A Plasma button swaps the water for one big plasma animation. It is a sum
    of sines sampled at each pixel's 3D position on the cube surface, so one
    continuous pattern flows over all six faces and across the edges. Works
    with the translucent and solid shell views and with the LEDs toggle.
    * Voxel Shell: every wall at least 1.0 mm (PCBWay review)
    PCBWay's thickness review flagged the 0.8 mm skin, the ledge where the
    outer funnel walls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
    [assembly_preview.stl, fit_test.stl, part_slide_switch_ss12f15.stl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]
2026-10-10 Add Voxel Shell 16x16 version for flexible 160 x 160 mm panels
    generate.py and check_fit.py take VOXEL_PROFILE=16x16 and write a 183.6 mm
    cube into case/voxel-shell-16x16/ (16x16 funnel cells, 174 mm lit area, same
    USB-C/switch bevel, four dowels per edge). The flexible panel is glued to a
    1 mm backing sheet so the panel stack stays 1.6 mm. The outer cells are pulled
    0.5 mm in from the square panel edge. All fit and 1.0 mm wall checks pass;
    the 8x8 geometry is unchanged.
    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
    [assembly_preview.stl, fit_test.stl, part_slide_switch_ss12f15.stl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]
2026-10-12 Replace Voxel Shell 16x16 with an 80 mm 8x8 panel version
    The second panel is an 8x8 flexible WS2812 panel, 80 x 80 mm with 10 mm
    pitch, not 16x16. Same firmware, two slightly different cases:
    - VOXEL_PROFILE=65mm (default): rigid 65 x 66 mm boards, 89.6 mm cube
    - VOXEL_PROFILE=80mm: flexible 80 x 80 mm on a 1 mm backing sheet,
    103.6 mm cube, 94 mm lit area, writes into case/voxel-shell-80mm/
    case/voxel-shell-16x16/ is removed. All fit and 1.0 mm wall checks pass for
    both profiles; the 65 mm STLs are unchanged.
    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
2026-10-12 Rename Voxel Shell to Voxel Shell 65x65 (and 80mm to 80x80)
    case/voxel-shell/ -> case/voxel-shell-65x65/, case/voxel-shell-80mm/ ->
    case/voxel-shell-80x80/; VOXEL_PROFILE values are now 65x65 (default) and
    80x80. Titles, Pages index and README links updated. Geometry unchanged;
    both profiles still pass check_fit.py.
    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
2026-10-23 Port firmware to ESP32-S3 with WLED-style panel chain
    - Target xtensa-esp32s3-none-elf; IMU SPI moved to GPIO 10-13 (LED data stays on 16)
    - Re-chain panels as Left, Front, Right, Back, Top, Bottom (OUT -> IN, row scan)
    - Add panel mapper tests (full LED coverage, chain corner adjacency)
    - BMI160: wait for accel to leave suspend, log power mode, SPI chip-ID probe
    - Stop sending a blank frame every cycle (fixes flicker)
    - Update README, CLAUDE.md and CI for the S3
2026-10-23 Make the fluid settle and stop LED flicker
    - Round particle positions to the nearest cell (truncation left the outer row
    flipping between 6 and 7)
    - Display hysteresis: a particle's LED moves only once it is clearly in the next cell
    - Position-based collisions: overlap-proportional push over 3 solver passes,
    velocity derived from actual displacement so blocked particles come to rest
    - Walls stop particles instead of bouncing them
    - Drop per-step logging from the fluid step
    - Tests: settled pile changes no LEDs, single particle rests on the floor
2026-10-24 Update LED color configuration for improved visibility and reduced power consumption
2026-10-25 Fix IMU X axis and speed up the fluid
    With panel 0 (x == 0) on the floor the BMI160 reads -1 g on X, so sensor X
    maps straight through to cube X instead of being negated. Verified on the
    hardware by laying the cube on its sides.
    Raise gravity to 0.15 and max velocity to 0.9 and drop the firmware frame
    delay to 0 ms so the particles move a lot faster.
2026-10-25 Speed up the fluid and react to shaking
    The collision solver dominated frame time on the ESP32-S3 (15.4 ms of a
    15.9 ms frame). Walk the grid cell by cell against the 13 forward
    neighbours so each pair is tested once, and replace sqrt plus a division
    with invsqrt, since the S3 FPU has neither in hardware. Build the core
    with opt-level 3. Physics is now 7.8 ms, about 120 fps.
    Raise gravity to 0.45 with a fourth solver pass so the pile still settles
    without flicker, use smoothing 0.85 and decay 0.98.
    Add MotionFilter, which tracks gravity slowly and amplifies motion on top,
    so shaking the cube sloshes the fluid. Read the IMU at +-4 g so shakes do
    not clip, and log physics and frame time.
    Co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
2026-10-26 Send LED frames from the second core
    Core 0 now runs the IMU and physics and builds each frame, then hands it
    to a task on core 1 over a one-slot channel. Core 1 sends it with the
    blocking RMT driver (~11.5 ms per changed frame), so physics and LED
    output overlap and the frame period becomes max(physics, LED) instead of
    their sum.
    The WS2812 adapter is split into FrameBuilder (panel mapping, core 0) and
    Ws2812Display (driver and unchanged-frame skipping, core 1). The status
    log now also reports the last LED send time.
2026-10-26 Use the gyro, swirl the fluid when spun, double tap to switch effect
    - Replace the bmi160 crate with a register-level SPI driver: accelerometer
    at 400 Hz, gyroscope at ±1000°/s with boot-time bias calibration, and the
    hardware double-tap engine polled from the latched INT_STATUS_0
    - MotionFilter turns its gravity estimate with the gyro (Rodrigues), so a
    tilt no longer lags and gets amplified as if it were a shake
    - SimulationEffect::set_rotation: the fluid lags against the cube's spin and
    is flung outwards; boids ignore it
    - EffectSwitcher cycles fluid/boids; a double tap on the cube or a double
    click on desktop switches, with a colour per effect
    - Desktop derives the per-frame s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
2026-10-26 Sweep the boids round when the cube spins
    Spinning carries the flock against the spin and out towards the walls,
    on top of the normal flocking rules. Also log the per-step wind at debug
    instead of info: it printed two lines every frame on the firmware UART.
2026-10-26 Add a starfield effect and register effects in one place
    Starfield: stars stream out of the centre and accelerate, respawning at
    the centre when they leave the cube. The field is fixed in the world:
    each step the star offsets are turned by the inverse of the cube's spin,
    so turning the cube turns it around the stars. Gravity is ignored.
    Effect handling: SimulationEffect is now object safe (boxed pixel
    iterator, name()), and EffectSwitcher holds a Box<dyn SimulationEffect>
    and dereferences to it. The effects, with their particle counts and
    colours, are listed once in switcher::effects(); firmware and desktop
    only pass a base Config. Adding an effect is its module plus one line.
    Colours are f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
2026-10-29 Fix SS12F15 switch pocket to the real switch size
    The switch body under the plate is the full 11.5 x 5.5 of the plate's
    middle section, not 8.6 x 3.6, so the printed pocket was too short and
    too narrow. Size the body pocket from the real body, add 2.5 mm behind
    the lugs for solder and wires, widen the lever slot to 7.0 for the
    3.3 mm lever, and run the wire channel and rim clearance as wide as the
    body so the longer pocket leaves no thin slivers.
    Claude-Session: https://claude.ai/code/session_01BWpaosRB6kgUA5d6DK28xZ
2026-10-29 Tighten the USB-C cut-out to the supplier drawing
    The cut-out was 14.6 x 8.6 for an assumed 9.3 mm flange, but the real
    socket body is 12.2 x 5.2 with an 8.2 mm flange: the printed hole had
    lots of play and the flange could not cover it. Use the drawing's
    14.2 x 5.4 panel cut-out (5.6 tall for resin), so the 15.6 mm snap wings
    catch and the flange laps it by 1.3 mm. The pocket behind the wall
    stays 8.6 tall; one just around the body leaves a thin wedge at the
    panel rim. Correct the reference socket model and the docs.
    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
2026-10-29 Close the gap beside the USB-C flange
    The pocket behind the USB-C wall was 8.6 tall on a 5 mm bevel, so it
    broke out through the front and bottom faces next to the flange (the
    flange sits flat on the bevel and cannot cover faces that fall away at
    45 degrees); the printed case showed a slot into the wiring there.
    Start the pocket at the cut-out height (5.5, the drawing's 14.2 x 5.4
    panel cut-out) and widen it at 45 degrees, parallel to the faces and
    1 mm under them, to its full 8.6. Flare the cut-out mouth at right
    angles to the faces so it meets them without a knife edge, under the
    flange. The wall the snap wings grip is now 1.7. The old strip opening
    and the _blunt wedge trimming are no lo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
